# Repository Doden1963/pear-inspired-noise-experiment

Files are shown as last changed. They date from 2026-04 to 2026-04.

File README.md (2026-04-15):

## 🔍 Overview

This project generates analog electronic noise using a zener diode, amplifies the signal, and samples it with a microcontroller.

The sampled signal is converted into a bitstream and analyzed statistically in real time using Python.

The focus is on building a complete measurement and data analysis system, working with real-time data, signal processing, and large datasets.

The project is inspired by experiments from the Princeton Engineering Anomalies Research (PEAR) lab.

⚠️ This project is exploratory and does **not claim proof** of any effect.

## 🎥 Video Demonstration

A short video showing a live run of the system:

Teensy Noise Experiment (https://youtu.be/2O-MlB6RiJg)

The video demonstrates:

- Real-time data acquisition from the hardware  
- Live accumulator behavior (UP / DOWN / NONE)  
- Statistical evolution during a run  

This provides a visual reference for how the system operates in practice.

## What this project demonstrates

- Hardware and software integration  
- Real-time data acquisition  
- Signal processing and statistical analysis  
- Working with large datasets in Python  
- Practical system development and debugging

## System Overview

Zener diode → Amplifier → Teensy ADC → Serial → Python → Analysis

## 📌 Inspiration

This project is inspired by the work of the Princeton Engineering Anomalies Research (PEAR) Lab.

The following video provides an overview of their experimental work and approach:

PEAR Lab video (https://www.youtube.com/watch?v=8A6pPLEzkhg)

### 🎞️ Interviews with Brenda Dunne (PEAR Lab)

This playlist includes three interviews with Brenda Dunne (PEAR Lab) on *New Thinking Allowed* with Jeffrey Mishlove.

The discussions cover experimental work on mind–matter interaction, methodology, and interpretation of results.

Brenda Dunne playlist (https://www.youtube.com/watch?v=D-jgZBlyOek&list=PL613Wzvi3ObDZJsnh43WpMpZ_Gc5zuUGy)

These materials provide useful background for understanding the context of this project.

---

## ⚙️ How It Works

### 🔌 Hardware Setup

The noise source is based on a reverse-biased zener diode, amplified and sampled by a Teensy 4.1.

---

### 🔹 PCB Implementation

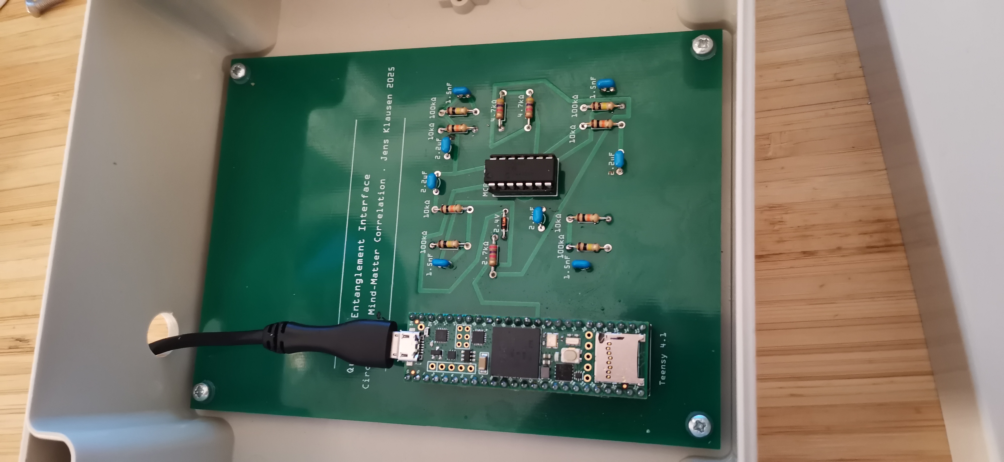
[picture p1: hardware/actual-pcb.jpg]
PCB view


The PCB provides a stable and low-noise implementation of the analog front-end, reducing interference and improving reproducibility.

---

### 🔹 Breadboard Prototype (Development)

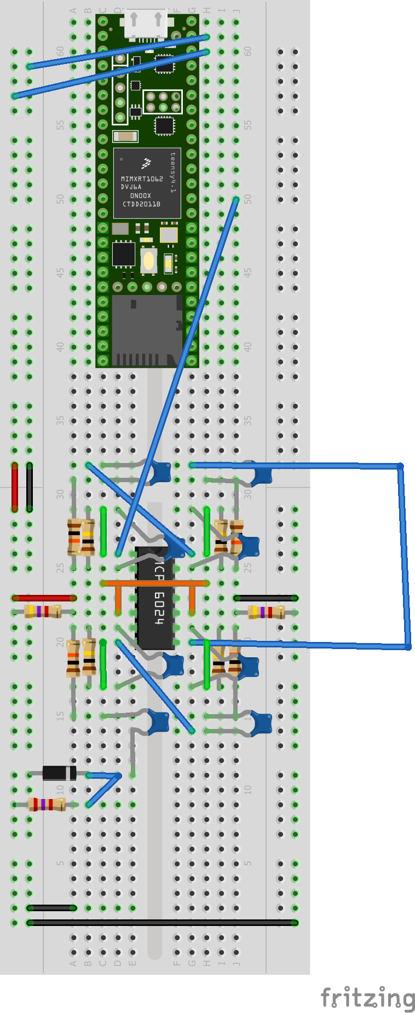
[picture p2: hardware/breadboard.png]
Breadboard view


Initial prototyping was performed on a breadboard. While flexible, this setup is more sensitive to noise and connection instability.

---

### Key components:

- Zener diode (noise source)  
- Multi-stage amplification (~10,000× gain)  
- Teensy 4.1 (12-bit ADC)  

---

### Notes

- The signal is extremely small before amplification  
- Physical layout significantly affects noise characteristics  
- Shielding and grounding are important for stable measurements   

### Sampling

- ~15,000 samples per second  
- 12-bit resolution (0–4095)  

### Bit Generation

- Least Significant Bit (LSB) extraction  
- Von Neumann debiasing  
  - 00 / 11 → discarded  
  - 01 → 0  
  - 10 → 1  

### Channels

- **UP** – condition A  
- **DOWN** – condition B  
- **NONE** – control condition  

---

## 📊 Example Results

This section shows selected visualizations from experimental runs.  
All plots are generated directly from recorded data and can be reproduced from the file in the `/data/logs` folder.

---

### 🔹 Combined Histograms (UP / DOWN / NONE)

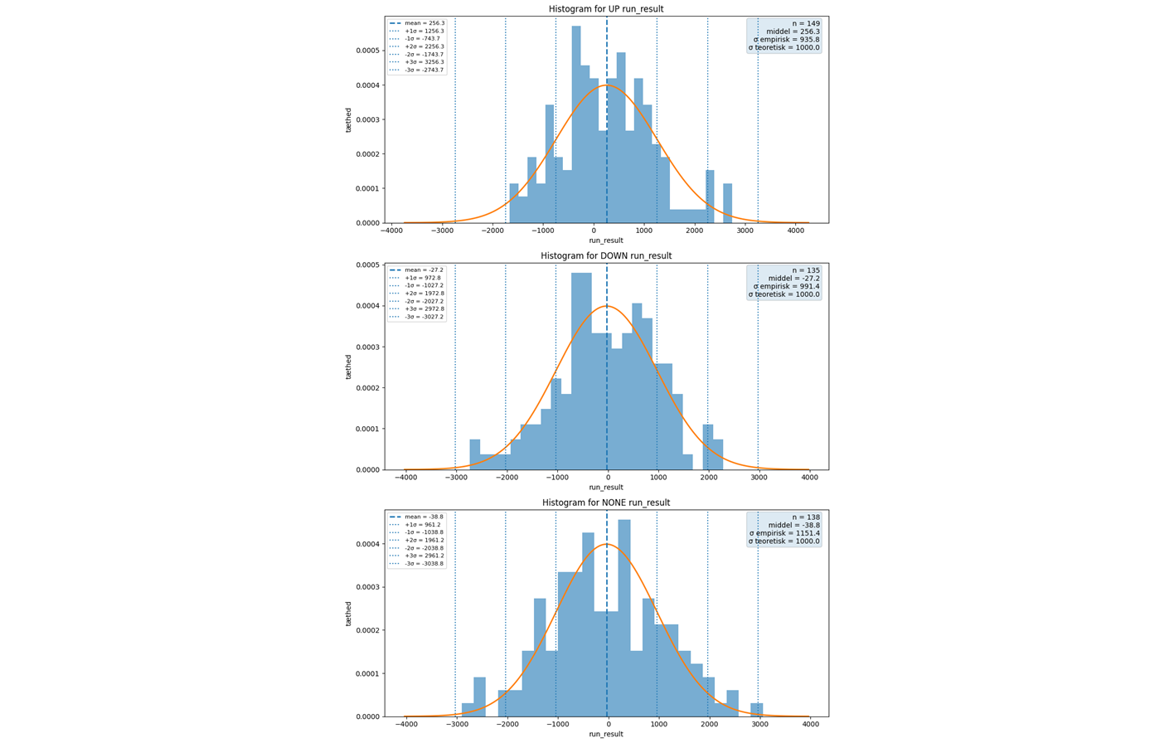
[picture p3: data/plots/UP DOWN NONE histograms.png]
UP DOWN NONE histograms


Histograms of run results for the three experimental conditions:

- **UP** – intention to increase the accumulator  
- **DOWN** – intention to decrease the accumulator  
- **NONE** – no intention (control condition)

Each histogram shows:

- Distribution of run results  
- Empirical mean  
- Empirical standard deviation (σ)  
- Theoretical σ (≈ 1000)  
- Reference lines for ±1σ, ±2σ, ±3σ  

**Observations:**

- Distributions are approximately normal  
- Means are close to zero  
- Empirical σ is close to theoretical values  

---

### 🔹 All Runs Histogram

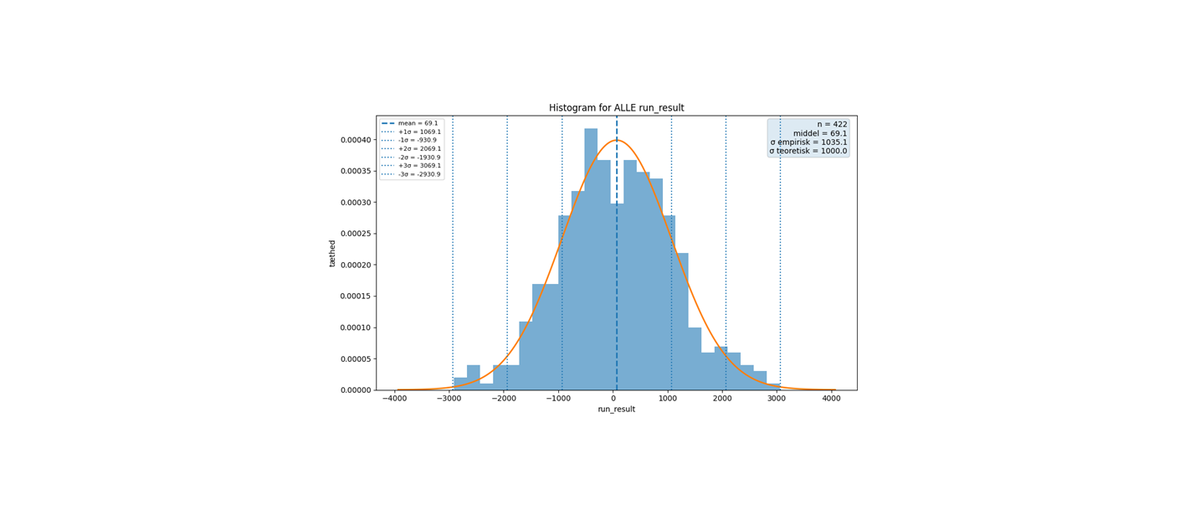
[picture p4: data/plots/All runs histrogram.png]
All runs histogram


Combined distribution across all runs:

- n = 422  
- Mean ≈ 69.1  
- Empirical σ ≈ 1035  
- Theoretical σ ≈ 1000  

The distribution is consistent with expected statistical behavior and shows no strong global bias.

---

### 🔹 Aggregated Accumulator Behavior (LSB + Von Neumann)

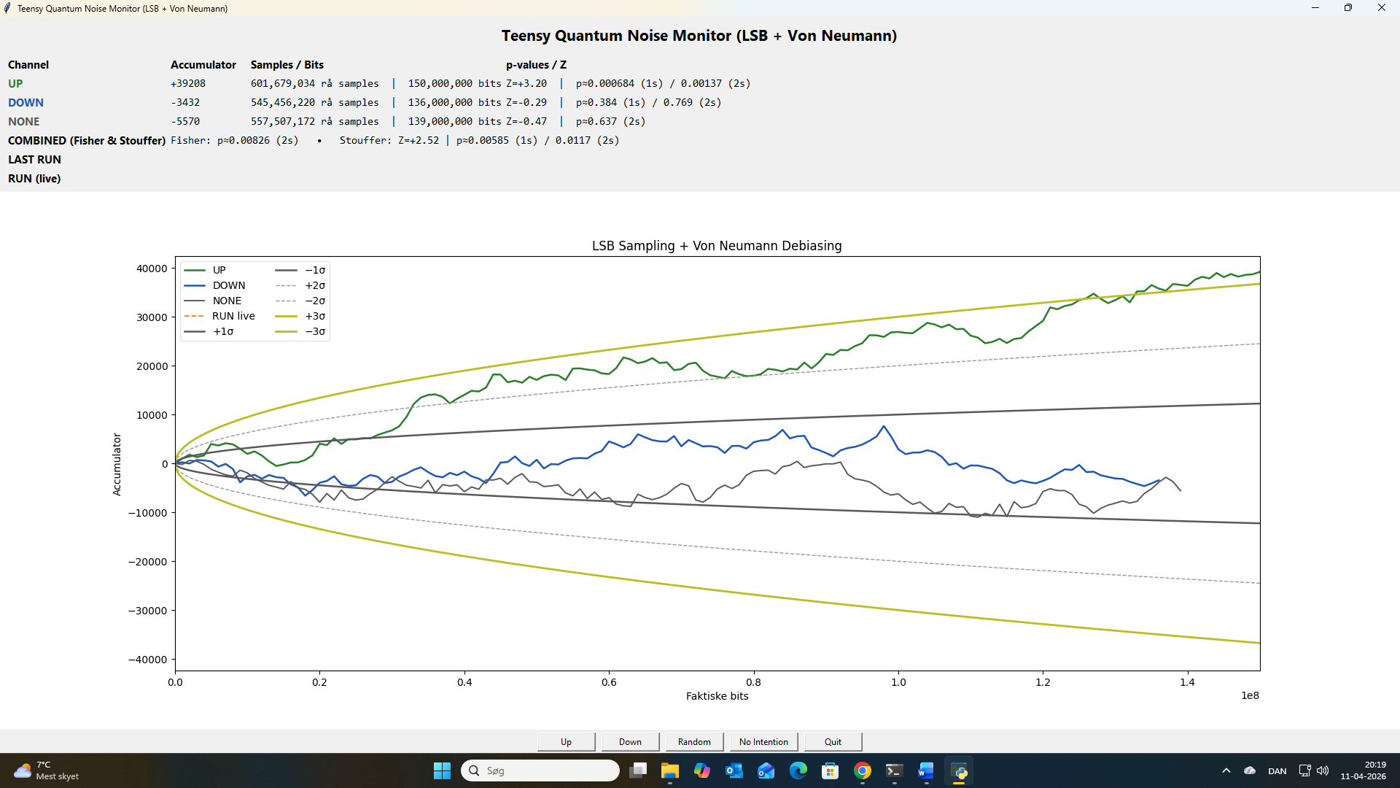
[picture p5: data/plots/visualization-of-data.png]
Accumulator plot


This plot shows the cumulative accumulator behavior across multiple runs.

The curves represent:

- **UP** – intention to increase the accumulator  
- **DOWN** – intention to decrease the accumulator  
- **NONE** – control condition  

Reference lines for ±1σ, ±2σ, and ±3σ indicate expected statistical boundaries.

---

### Observations

- The **UP curve reaches approximately z ≈ +3.2**, indicating a notable cumulative deviation  
- The **DOWN** and **NONE** curves remain close to expected statistical limits  
- Fluctuations occur over time, consistent with stochastic processes  

---

### Interpretation

- A z-score of ~3.2 corresponds to a low-probability event under pure randomness  
- However, this result reflects **accumulated data across runs**, not a single independent trial  
- Proper statistical interpretation requires careful consideration of:
  - independence of runs  
  - multiple testing effects  
  - long-term reproducibility  

---

### Notes

- This visualization aggregates data across runs  
- It should not be interpreted as a single continuous experiment  
- Individual run statistics are available in `/data/logs/`  

---

## 🧪 Experimental Notes

- Individual runs can reach z ≈ 2–3 by chance  
- Statistical interpretation requires many independent runs  
- Von Neumann debiasing reduces bias but lowers bit rate  
- Small mean offsets are expected in finite datasets  

---

## 📁 Project Structure

```
pear-inspired-noise-experiment/
│
├── data/
│   ├── logs/          # Statistical results
│   └── plots/         # Generated plots (histograms, run visuals)
│
├── firmware/          # Teensy 4.1 code (data acquisition)
│
├── hardware/          # Circuit design and hardware documentation
│
├── software/          # Python GUI, processing, and analysis
│
└── README.md
```

---

## 🎯 Purpose

This project aims to:

- Build a transparent and reproducible measurement system  
- Explore statistical properties of physical noise  
- Test for possible deviations under different experimental conditions  

---

## ⚠️ Disclaimer

This project is exploratory and should not be interpreted as evidence of causal effects without rigorous statistical validation and independent replication.

---

## 📬 Contributions

Suggestions, critiques, and replication attempts are welcome.

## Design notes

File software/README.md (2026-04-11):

# Software (Python / Jupyter)

This folder contains Jupyter notebooks used to analyze noise data generated by the Teensy 4.1 system.

The analysis focuses on bit extraction, statistical evaluation, and visualization of noise behavior.

---

## Files

* `lsb_ratio_1M_samples.ipynb`
  Calculates the ratio between 0 and 1 bits from a large sample set (e.g. 1,000,000 samples)

* `pear_experiment_15000hz_von_neumann.ipynb`
  Main experiment using high sample rate data and Von Neumann debiasing

* `historical_histograms.ipynb`
  Displays histograms of accumulated data to visualize statistical distributions

* `teensy_samples_150.ipynb`
  Inspection of raw data samples from the Teensy device

* `lowpass_audio_analysis.ipynb`
  Analysis of filtered signals and optional audio output

---

## Methods

The notebooks implement several key steps:

* Conversion of analog noise into digital bits
* Bit extraction using LSB and derived methods
* Optional debiasing (e.g. Von Neumann)
* Statistical evaluation using z-score and p-values
* Visualization using histograms and plots

---

## Data Source

* Data is collected from the Teensy 4.1 via serial communication
* Typical sampling rates include high-frequency acquisition (e.g. ~15,000 samples/sec)

---

## Notes

* Results should be interpreted statistically
* Random fluctuations are expected in finite samples
* Hardware setup (breadboard vs PCB) can influence results
* Noise characteristics depend on analog amplification and environment

---

## Usage

Open the notebooks using Jupyter:

```id="run_nb"
jupyter notebook
```

or

```id="run_nb2"
jupyter lab
```

Then run the cells step by step.

---

## Purpose

The goal of this software is to analyze whether statistical deviations from randomness occur under different experimental conditions (e.g. UP, DOWN, NONE).

---

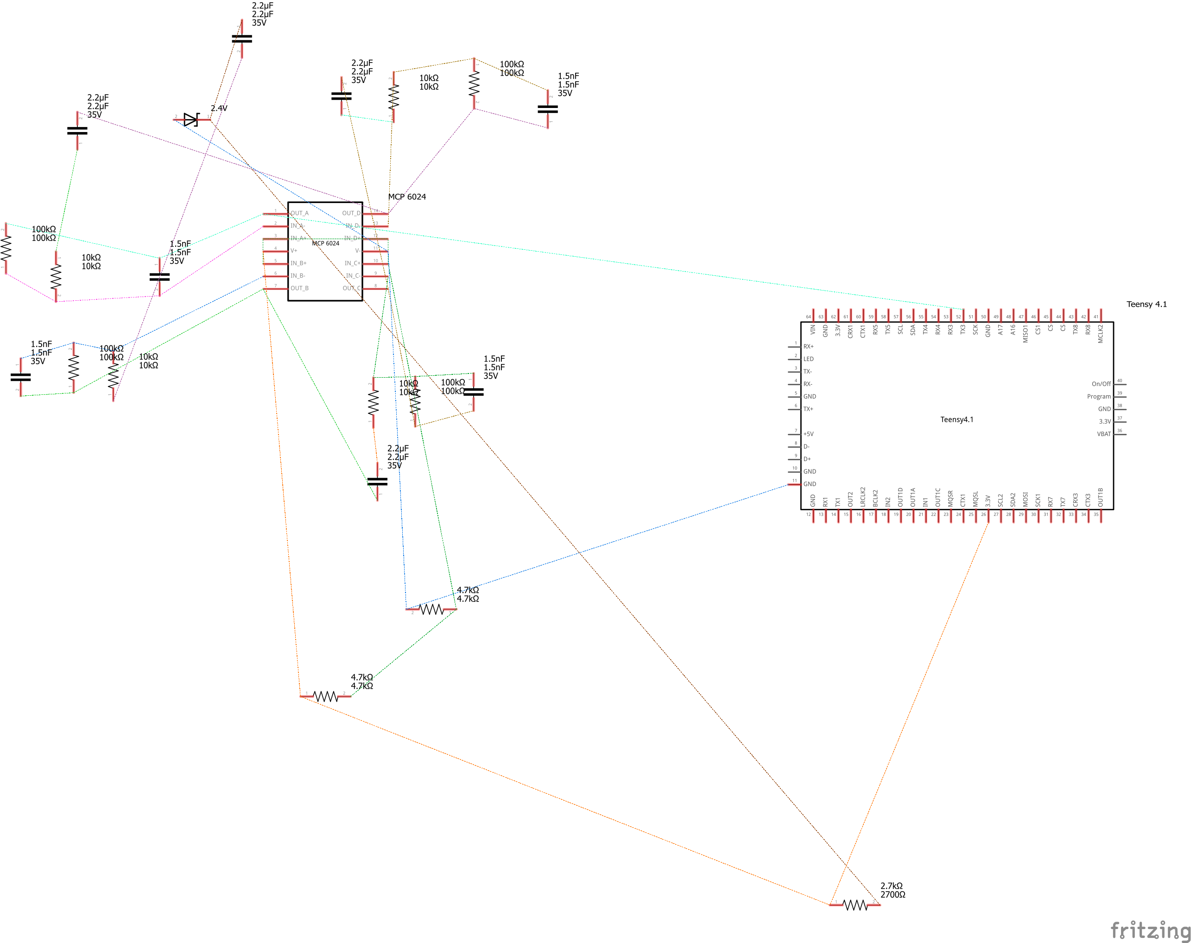
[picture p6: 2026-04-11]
hardware/schematic.png

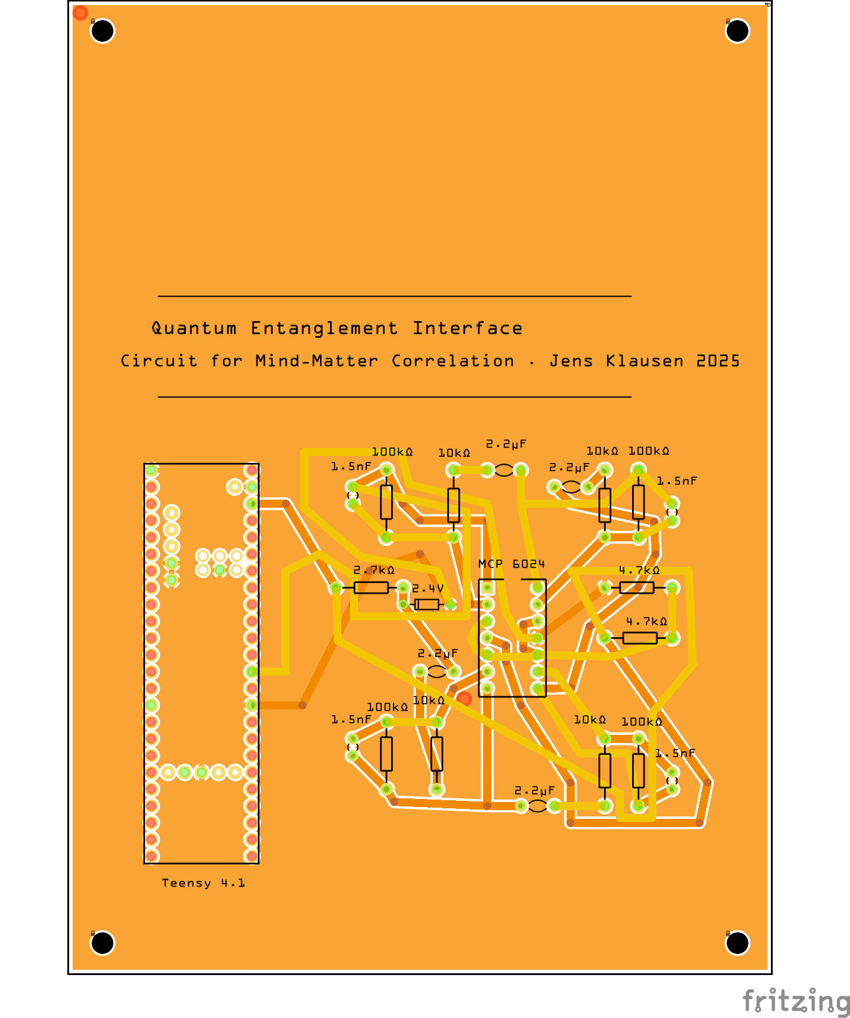
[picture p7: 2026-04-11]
hardware/pcb.png

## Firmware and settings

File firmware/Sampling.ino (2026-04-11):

/*
  Teensy 4.x ADC DMA example med PC-styret START/N blokke via USB-serial
  Kræver ADC_USE_DMA og ADC_USE_TIMER
*/

#include <ADC.h>
#if defined(ADC_USE_DMA) && defined(ADC_USE_TIMER)
#include <AnalogBufferDMA.h>
#include <DMAChannel.h>

// Pin-konfiguration
#ifdef ADC_DUAL_ADCS
  const int readPin_adc_0 = A0;
  const int readPin_adc_1 = A2;
#else
  const int readPin_adc_0 = A0;
  const int readPin_adc_1 = 26;
#endif

// Hvor mange samples per blok
const uint32_t buffer_size = 1500;
const float    Fs          = 15000.0f;  // samplingfrekvens i Hz
// DMA-bufferindstillinger
DMAMEM static volatile uint16_t __attribute__((aligned(32)))
  dma0_buf1[buffer_size], dma0_buf2[buffer_size];
AnalogBufferDMA abdma1(dma0_buf1, buffer_size,
                       dma0_buf2, buffer_size);

#ifdef ADC_DUAL_ADCS
DMAMEM static volatile uint16_t __attribute__((aligned(32)))
  dma1_buf1[buffer_size], dma1_buf2[buffer_size];
AnalogBufferDMA abdma2(dma1_buf1, buffer_size,
                       dma1_buf2, buffer_size);
#endif

// ADC-objekt
ADC *adc = new ADC();

// Styring af streaming
volatile int  blocksToStream  = 0;
volatile int  blocks0Streamed = 0;
volatile int  blocks1Streamed = 0;
volatile bool sampling        = false;
elapsedMillis idle_timer;

volatile uint32_t block_id_0 = 0;
#ifdef ADC_DUAL_ADCS
volatile uint32_t block_id_1 = 0;
#endif

// Forward declaration
void ProcessAnalogData(AnalogBufferDMA *pab, int8_t adc_num);

void setup() {
  Serial.begin(9600);
  while (!Serial && millis() < 5000);

  pinMode(LED_BUILTIN, OUTPUT);
  pinMode(readPin_adc_0, INPUT_DISABLE);
#ifdef ADC_DUAL_ADCS
  pinMode(readPin_adc_1, INPUT_DISABLE);
#endif

  Serial.println("Teensy klar til START N / STOP-kommandoer");

  // Konfigurer ADC, men start ikke timer endnu
  adc->adc0->setAveraging(1);
  adc->adc0->setResolution(12);
#ifdef ADC_DUAL_ADCS
  adc->adc1->setAveraging(1);
  adc->adc1->setResolution(12);
#endif

  // Initialiser DMA
  abdma1.init(adc, ADC_0);
#ifdef ADC_DUAL_ADCS
  abdma2.init(adc, ADC_1);
#endif
   // Send sampling-parametre til PC
               // samme som du bruger i startTimer()
  //Serial.printf("FS=%.0f\n", Fs);
  //Serial.printf("BS=%u\n", buffer_size);
  idle_timer = 0;
}


void loop() {
  // 1) Håndter START N og STOP fra PC
  if (Serial.available()) {
    String cmd = Serial.readStringUntil('\n');
    cmd.trim();
    if (cmd.startsWith("START")) {
      int n = 1;
      if (cmd.length() > 6) {
        n = cmd.substring(6).toInt();
      }
      if (n > 0 && !sampling) {
        // Sæt op til streaming af n blokke pr. kanal
        blocksToStream   = n;
        blocks0Streamed  = 0;
        blocks1Streamed  = 0;
        sampling         = true;

        block_id_0 = 0;
      #ifdef ADC_DUAL_ADCS
        block_id_1 = 0;
      #endif

        // Ryd DMA-interrupts
        abdma1.clearInterrupt();
#ifdef ADC_DUAL_ADCS
        abdma2.clearInterrupt();
#endif

        // Start første blok på begge ADC’er
        adc->adc0->startSingleRead(readPin_adc_0);
        adc->adc0->startTimer(Fs);
#ifdef ADC_DUAL_ADCS
        adc->adc1->startSingleRead(readPin_adc_1);
        adc->adc1->startTimer(Fs);
#endif

        Serial.printf("START %d blokke pr. kanal\n", n);
      }
    }
    else if (cmd.equalsIgnoreCase("STOP") && sampling) {
      // Stop streaming øjeblikkeligt
      adc->adc0->stopTimer();
#ifdef ADC_DUAL_ADCS
      adc->adc1->stopTimer();
#endif
      sampling = false;
      Serial.println("STOP PET");
    }
  }

  // 2) Under sampling: håndter DMA-interrupts og blok–tællere
  if (sampling) {
    // ADC0
    if (abdma1.interrupted()) {
      ProcessAnalogData(&abdma1, 0);
      abdma1.clearInterrupt();
      blocks0Streamed++;
    }
    // ADC1 (hvis tilgængelig)
#ifdef ADC_DUAL_ADCS
    if (abdma2.interrupted()) {
      ProcessAnalogData(&abdma2, 1);
      abdma2.clearInterrupt();
      blocks1Streamed++;
    }
#endif

    // 3) Stop automatisk når begge kanaler har nået quota
    bool done0 = (blocks0Streamed >= blocksToStream);
#ifdef ADC_DUAL_ADCS
    bool done1 = (blocks1Streamed >= blocksToStream);
    if (done0 && done1) {
#else
    if (done0) {
#endif
      adc->adc0->stopTimer();
#ifdef ADC_DUAL_ADCS
      adc->adc1->stopTimer();
#endif
      sampling = false;
      Serial.println("FÆRDIG med alle blokke");
    }

    // Nulstil idle–timer ved aktivitet
    idle_timer = 0;
  }
  // 4) Heartbeat når inaktiv
  else if (idle_timer > 5000) {
    digitalWriteFast(LED_BUILTIN, HIGH);
    delay(100);
    digitalWriteFast(LED_BUILTIN, LOW);
    delay(100);
    idle_timer = 0;
  }
}



// --- Funktion, der sender én blok via USB-serial ---
void ProcessAnalogData(AnalogBufferDMA *pab, int8_t adc_num) {
  volatile uint16_t *buf = pab->bufferLastISRFilled();
  size_t count = pab->bufferCountLastISRFilled();

  if ((uint32_t)buf >= 0x20200000u) {
    arm_dcache_delete((void*)buf, count * sizeof(uint16_t));
  }

  uint32_t bid;
  if (adc_num == 0) {
    bid = block_id_0++;
  }
#ifdef ADC_DUAL_ADCS
  else {
    bid = block_id_1++;
  }
#else
  else {
    bid = 0;
  }
#endif

  uint8_t header[8] = {
    0x7E,
    (uint8_t)adc_num,
    (uint8_t)(count >> 8),
    (uint8_t)(count & 0xFF),
    (uint8_t)(bid >> 24),
    (uint8_t)(bid >> 16),
    (uint8_t)(bid >> 8),
    (uint8_t)(bid & 0xFF)
  };

  Serial.write(header, 8);
  Serial.write((uint8_t*)buf, count * sizeof(uint16_t));

  pab->clearInterrupt();
}

#else
void setup() {}
void loop() {}
#endif // ADC_USE_DMA & ADC_USE_TIMER

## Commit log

2026-04-11 Rename Støjgenerator med Teensy 41 til produktion_bb.png to breadboard.png
2026-04-11 Rename Støjgenerator med Teensy 41 til produktion_schem.png to schematic.png
2026-04-11 Rename Støjgenerator med Teensy 41 til produktion_pcb.png to pcb.png
2026-04-11 Rename Stoejgenerator med Teensy til produktion 01.zip to gerbers.zip
2026-04-11 Rename Støjgenerator med Teensy 41 til produktion.fzz to noise_generator.fzz
    [noise_generator.fzz]
2026-04-11 Rename LSB 0 og 1 forhold af 1000000 samples.ipynb to lsb_ratio_1M_samples.ipynb
2026-04-11 Rename Pear Lab inspireret 15000 Hz data i accum_log-no_lowpass-LSB-von-neumann nyeste.ipynb to pear_experiment_15000hz_von_neumann.ipynb
2026-04-11 Rename Samples fra teensy 150.ipynb to teensy_samples_150.ipynb
2026-04-11 Rename Viser data fra Teensy også med lavpas filter og lyd nyeste.ipynb to lowpass_audio_analysis.ipynb
